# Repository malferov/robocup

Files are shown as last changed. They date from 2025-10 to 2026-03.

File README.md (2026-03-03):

# RoboCup Junior

Netherlands team CoreX

<p align="center">
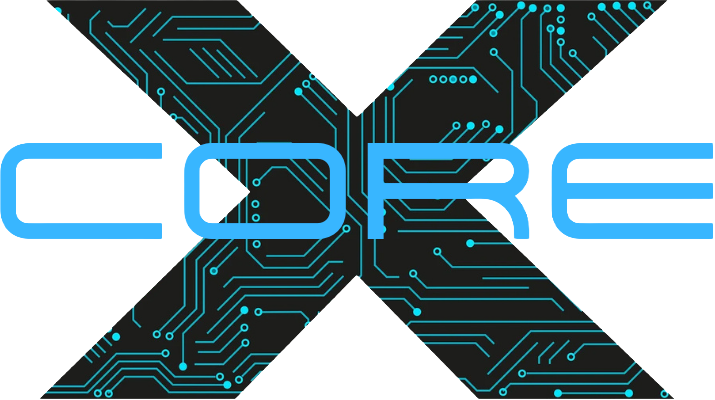
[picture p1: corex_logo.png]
CoreX
    
</p>

# Components
- 25mm DC 12V GA-370 Low Speed Metal Gear Motor 400RPM 3.5 Watts 90 g
- TB6612FNG Dual Driver Controller Board MOSFET H Bridge 15V max VCC=2.7-5.5V Output 1.2A/3.2A
- 12.6V 3000mAh Lithium Ion Battery 157 g
- OT253-B47 Step-down buck converter 4.5-24V to 5V 3A
- HC-SR04 Ultrasonic Sensor
- TCRT5000 Reflective Infrared Optical Sensor
- TSSP4038, 38kHz IR Receiver, 950nm ±45°, 25m Range, 2.5-5.5V
- HC4067 16-channel Analog Multiplexer
- BMM150 Triple Axis Magnetometer Sensor
- MCU: ESP32-S3

# Metrics
### Consumption
- Main + CAM + Driver: 170 mA
### Performance
- Distance sensor: 33 ms
- Camera capture: 34 ms
- get_pos: 98 ms

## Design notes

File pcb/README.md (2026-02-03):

# CNC

lift tool `G0 Z5`  
return to origin `G0 X0 Y0`

# PCB

default net class
- clearance 0.5 mm
- track width 1 mm
- via size 2 mm
- via hole 0.8

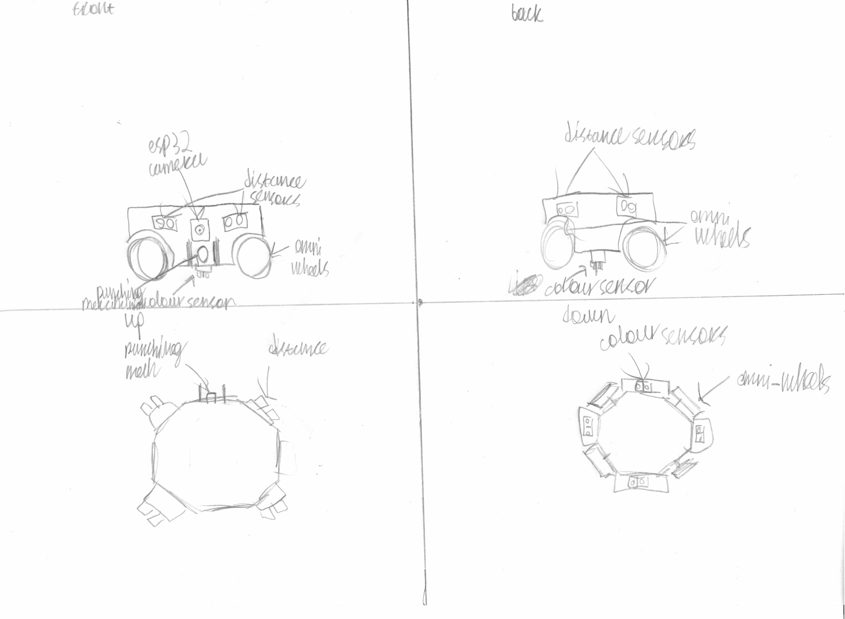
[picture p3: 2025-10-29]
docs/design_concept.jpg

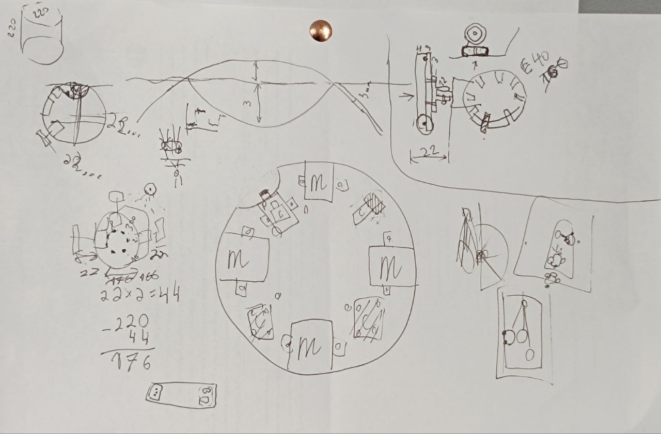
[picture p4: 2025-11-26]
docs/design_body.jpg

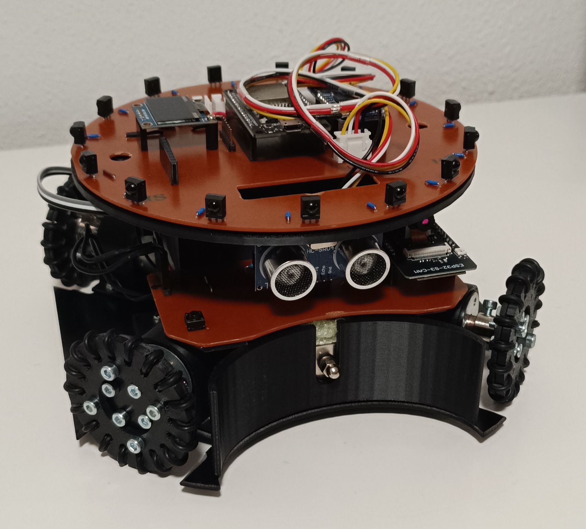
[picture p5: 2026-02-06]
docs/bot1.jpg

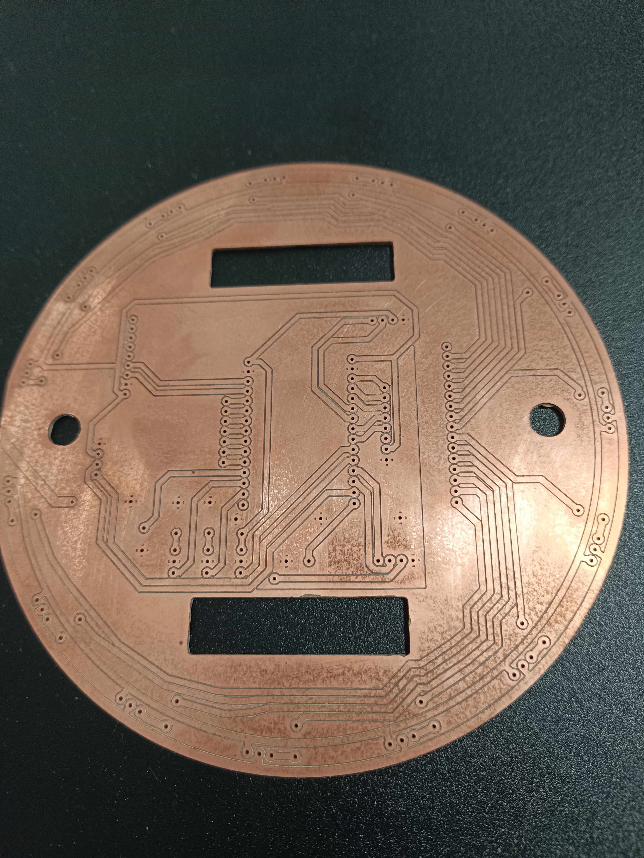
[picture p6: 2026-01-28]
docs/mainboard.jpg

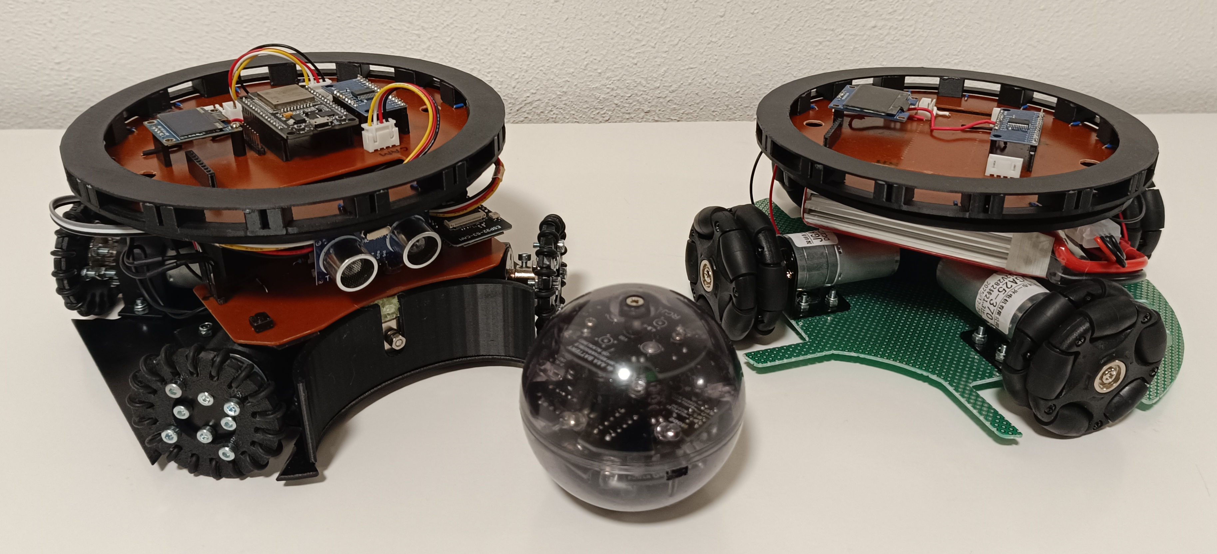
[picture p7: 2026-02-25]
docs/robots.jpg

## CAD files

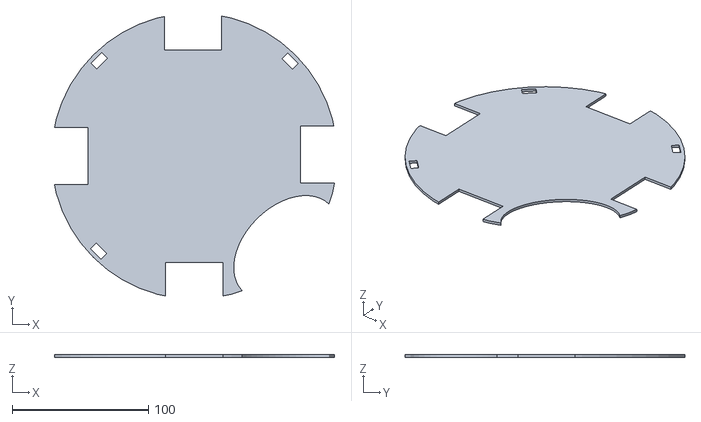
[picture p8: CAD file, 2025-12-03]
pintables/body/body.stl
205.6 x 205.5 x 2.00

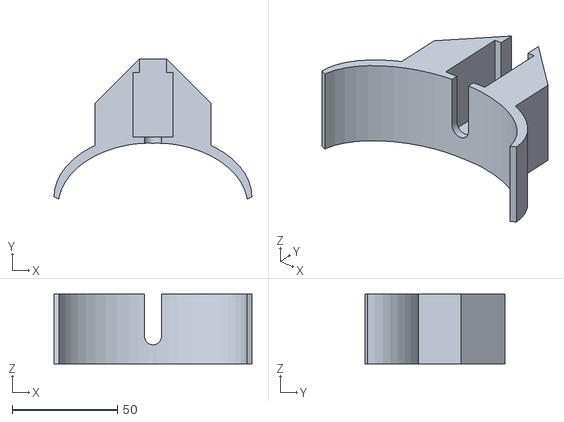
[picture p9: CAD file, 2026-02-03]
pintables/front_bumper.stl
94.0 x 66.6 x 33.0

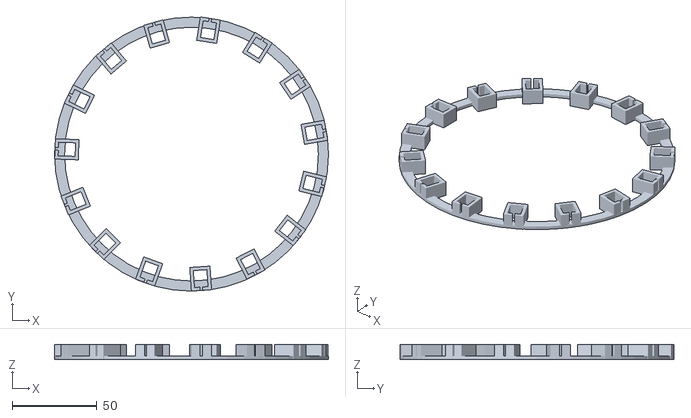
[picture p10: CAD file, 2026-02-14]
pintables/IRcase/IR_case.stl
162.0 x 162.1 x 9.00

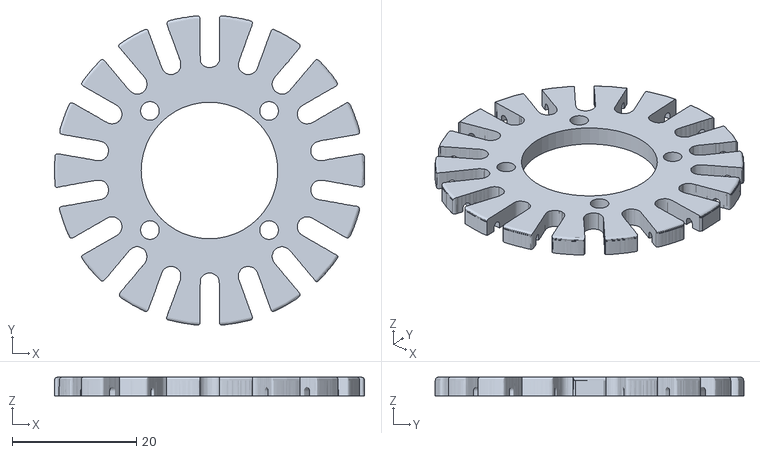
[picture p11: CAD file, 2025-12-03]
pintables/wheel/star_cap.stl
50.0 x 49.8 x 3.00

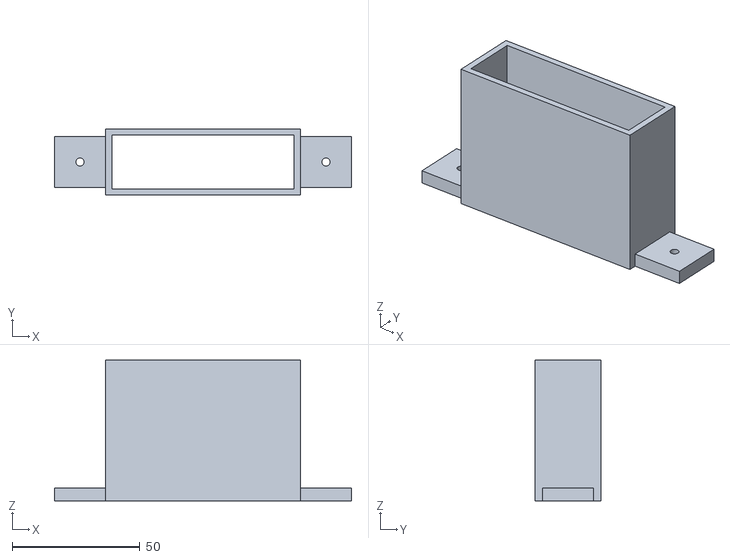
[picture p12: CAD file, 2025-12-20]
pintables/battery_holder.stl
116.3 x 26.0 x 55.2

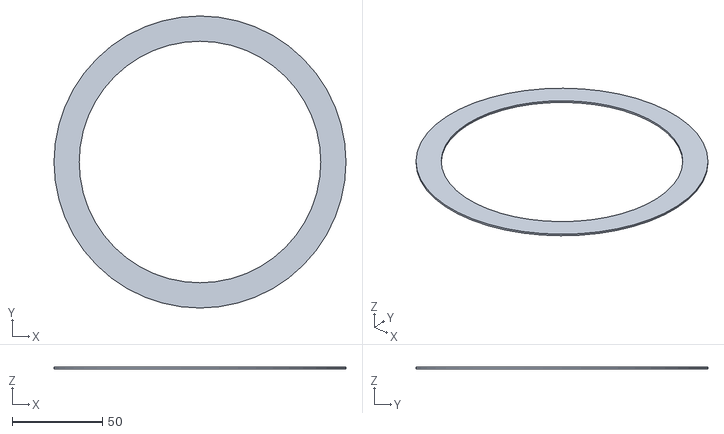
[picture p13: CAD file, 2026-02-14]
pintables/IRcase/IR_case_top.stl
162.0 x 162.0 x 1

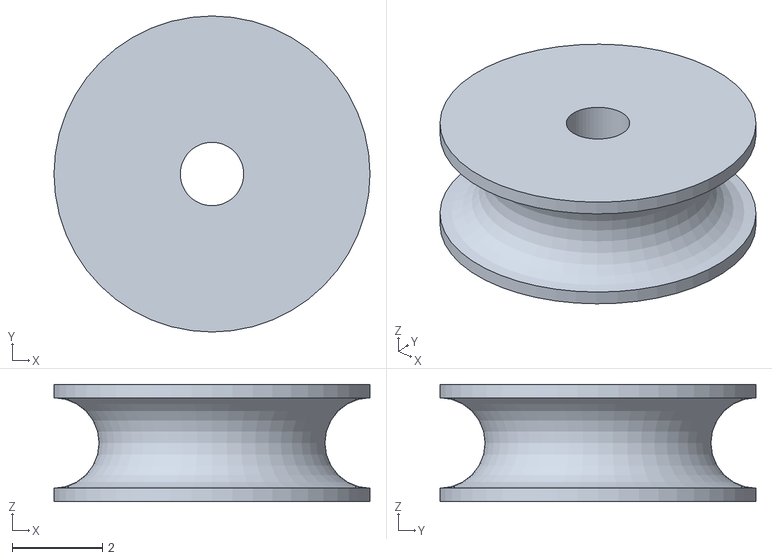
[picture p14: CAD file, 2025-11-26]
pintables/wheel/pulley.stl
7.00 x 7.00 x 2.60

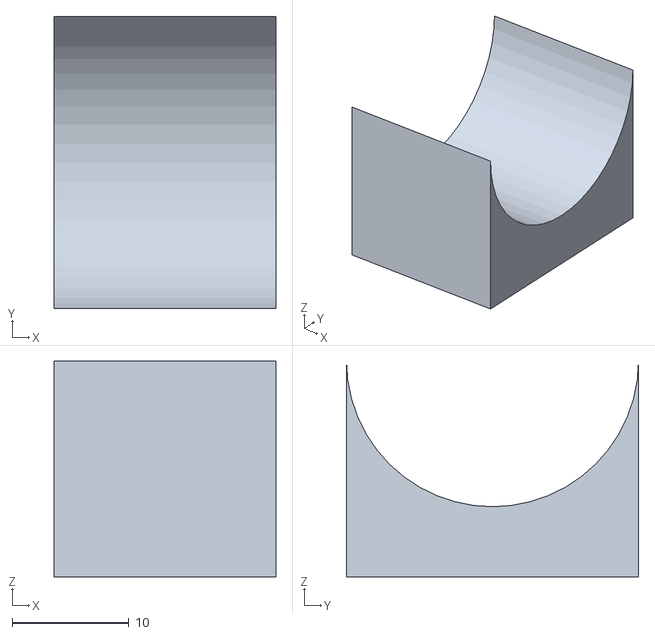
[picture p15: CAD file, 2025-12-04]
pintables/support.stl
19.0 x 25.0 x 18.5

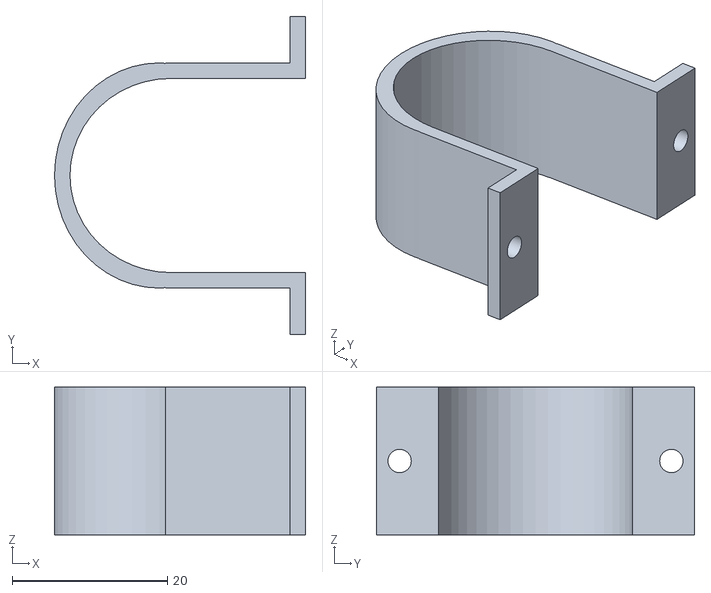
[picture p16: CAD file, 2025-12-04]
pintables/arc.stl
32.3 x 41.0 x 19.0

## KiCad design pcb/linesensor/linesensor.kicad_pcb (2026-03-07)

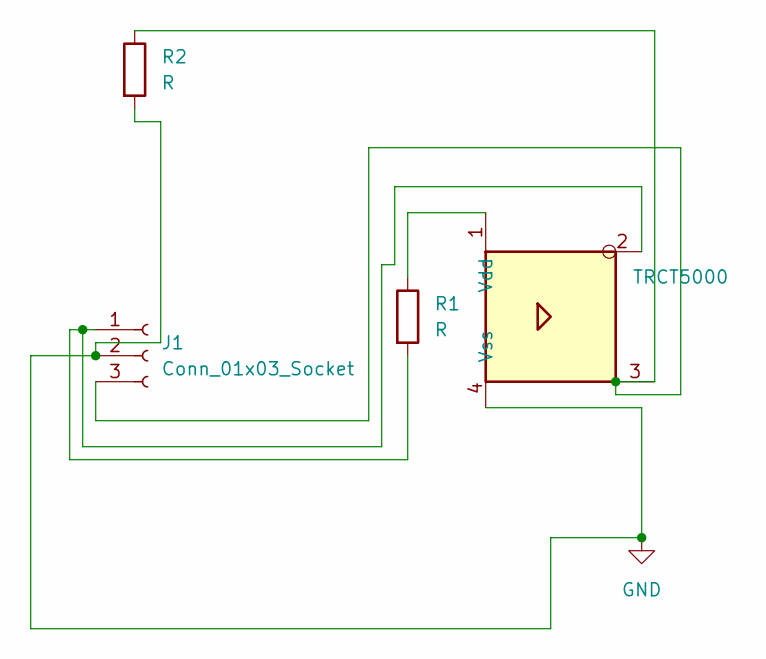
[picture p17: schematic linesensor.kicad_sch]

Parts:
J1: Conn_01x03_Socket; PinSocket_1x03_P2.54mm_Vertical
R1, R2: R; R_Axial_DIN0309_L9.0mm_D3.2mm_P12.70mm_Horizontal
U1: TRCT5000; CRT5000

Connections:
GND: J1.2, R2.2, U1.4 (Vss)
unnamed: J1.1, R1.2, U1.2
unnamed: J1.3, R2.1, U1.3
unnamed: R1.1, U1.1 (Vdd)

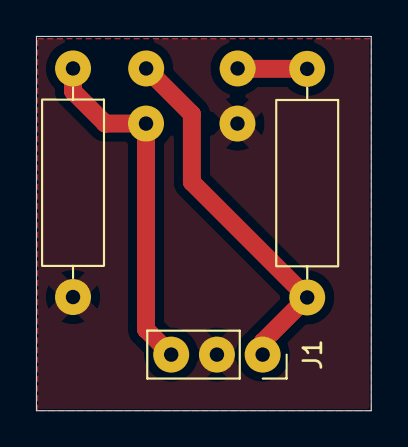
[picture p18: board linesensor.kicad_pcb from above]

Board: 2 copper layers, 18.6 x 20.8 mm, 4 parts (0 on the bottom side), 4 nets.

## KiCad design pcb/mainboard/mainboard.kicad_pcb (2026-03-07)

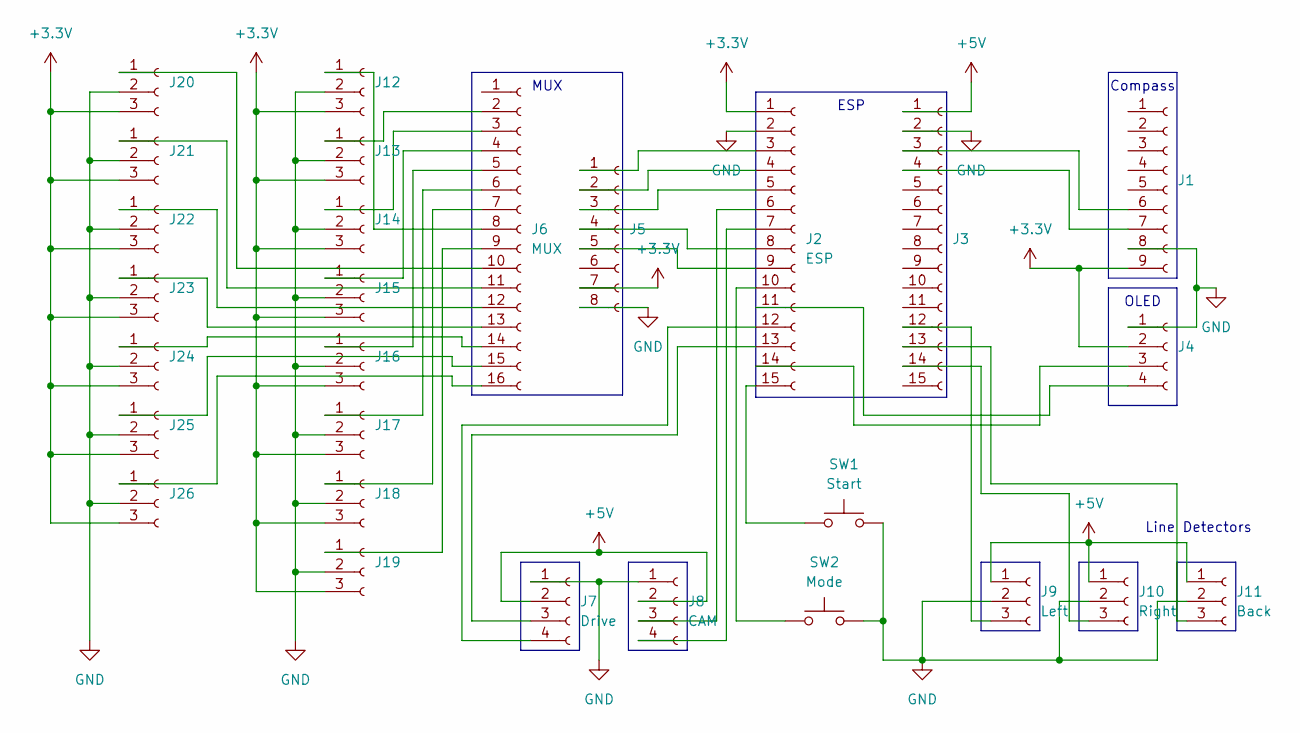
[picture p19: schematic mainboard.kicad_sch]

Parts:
J1: Compass; PinSocket_1x09_P2.54mm_Vertical
J2: ESP; PinSocket_1x15_P2.54mm_Vertical
J3: ESP_; PinSocket_1x15_P2.54mm_Vertical
J4: OLED; PinSocket_1x04_P2.54mm_Vertical
J5: MUX_; PinSocket_1x08_P2.54mm_Vertical
J6: MUX; PinSocket_1x16_P2.54mm_Vertical
J7: Drive; PinSocket_1x04_P2.54mm_Vertical
J8: CAM; PinSocket_1x04_P2.54mm_Vertical
J9: Left; PinSocket_1x03_P2.54mm_Vertical
J10: Right; PinSocket_1x03_P2.54mm_Vertical
J11: Back; PinSocket_1x03_P2.54mm_Vertical
J12, J13, J14, J15, J16, J17, J18, J19, J20, J21, J22, J23, J24, J25, J26: Conn_01x03_Socket; PinSocket_1x03_P2.54mm_Vertical
SW1: Start; D_5W_P5.08mm_Vertical_AnodeUp
SW2: Mode; D_5W_P5.08mm_Vertical_AnodeUp

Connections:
+3.3V: J1.9, J2.1, J4.2, J5.7, J12.3, J13.3, J14.3, J15.3, J16.3, J17.3, J18.3, J19.3, J20.3, J21.3, J22.3, J23.3, J24.3, J25.3, J26.3
+5V: J3.1, J7.2, J8.2, J9.1, J10.1, J11.1
GND: J1.8, J2.2, J3.2, J4.1, J5.8, J7.1, J8.1, J9.2, J10.2, J11.2, J12.2, J13.2, J14.2, J15.2, J16.2, J17.2, J18.2, J19.2, J20.2, J21.2, J22.2, J23.2, J24.2, J25.2, J26.2, SW1.2, SW2.2
unnamed: J1.6, J3.3
unnamed: J1.7, J3.4
unnamed: J2.3, J5.1
unnamed: J2.4, J5.2
unnamed: J2.5, J5.3
unnamed: J2.6, J8.3
unnamed: J2.7, J8.4
unnamed: J2.8, J5.4
unnamed: J2.9, J5.5
unnamed: J2.10, SW2.1
unnamed: J2.11, J4.4
unnamed: J2.12, J7.4
unnamed: J2.13, J7.3
unnamed: J2.14, J4.3
unnamed: J2.15, SW1.1
unnamed: J3.12, J9.3
unnamed: J3.14, J10.3
unnamed: J3.13, J11.3
unnamed: J6.8, J12.1
unnamed: J6.2, J13.1
unnamed: J6.3, J14.1
unnamed: J6.4, J15.1
unnamed: J6.5, J16.1
unnamed: J6.6, J17.1
unnamed: J6.7, J18.1
unnamed: J6.9, J19.1
unnamed: J6.10, J20.1
unnamed: J6.11, J21.1
unnamed: J6.12, J22.1
unnamed: J6.13, J23.1
unnamed: J6.14, J24.1
unnamed: J6.15, J25.1
unnamed: J6.16, J26.1

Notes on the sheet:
Line Detectors
OLED
Compass
ESP
MUX

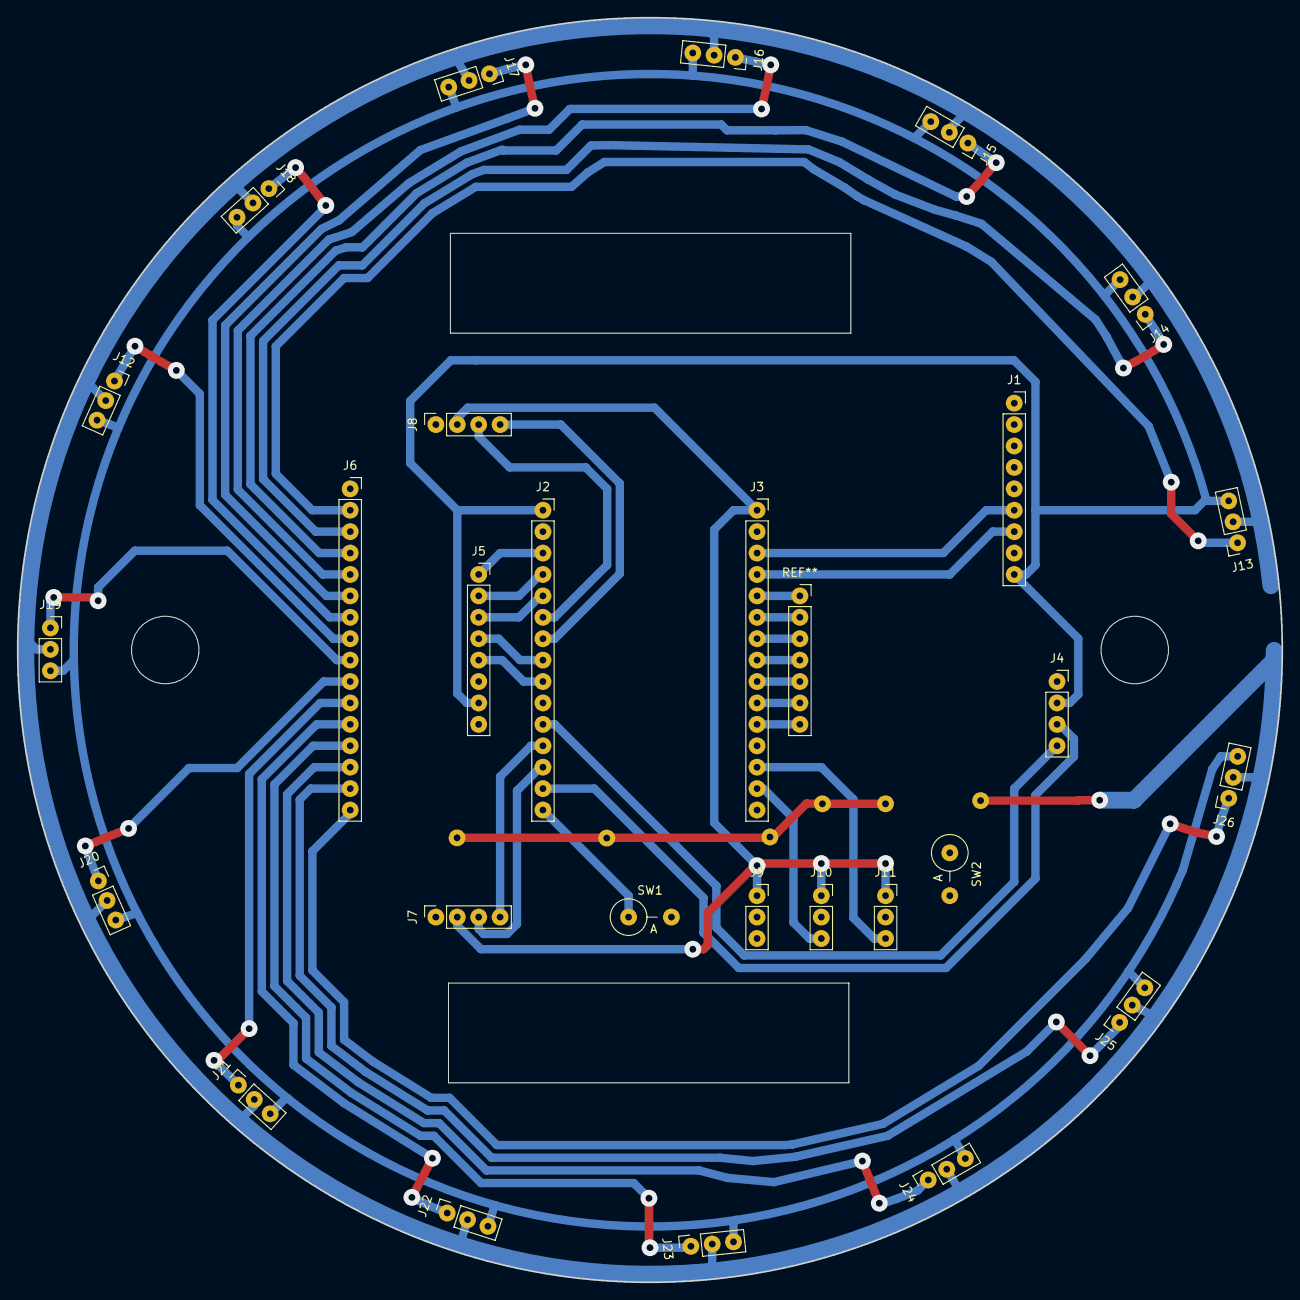
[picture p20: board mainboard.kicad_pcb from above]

Board: 2 copper layers, 150.0 x 150.0 mm, 28 parts (0 on the bottom side), 36 nets.

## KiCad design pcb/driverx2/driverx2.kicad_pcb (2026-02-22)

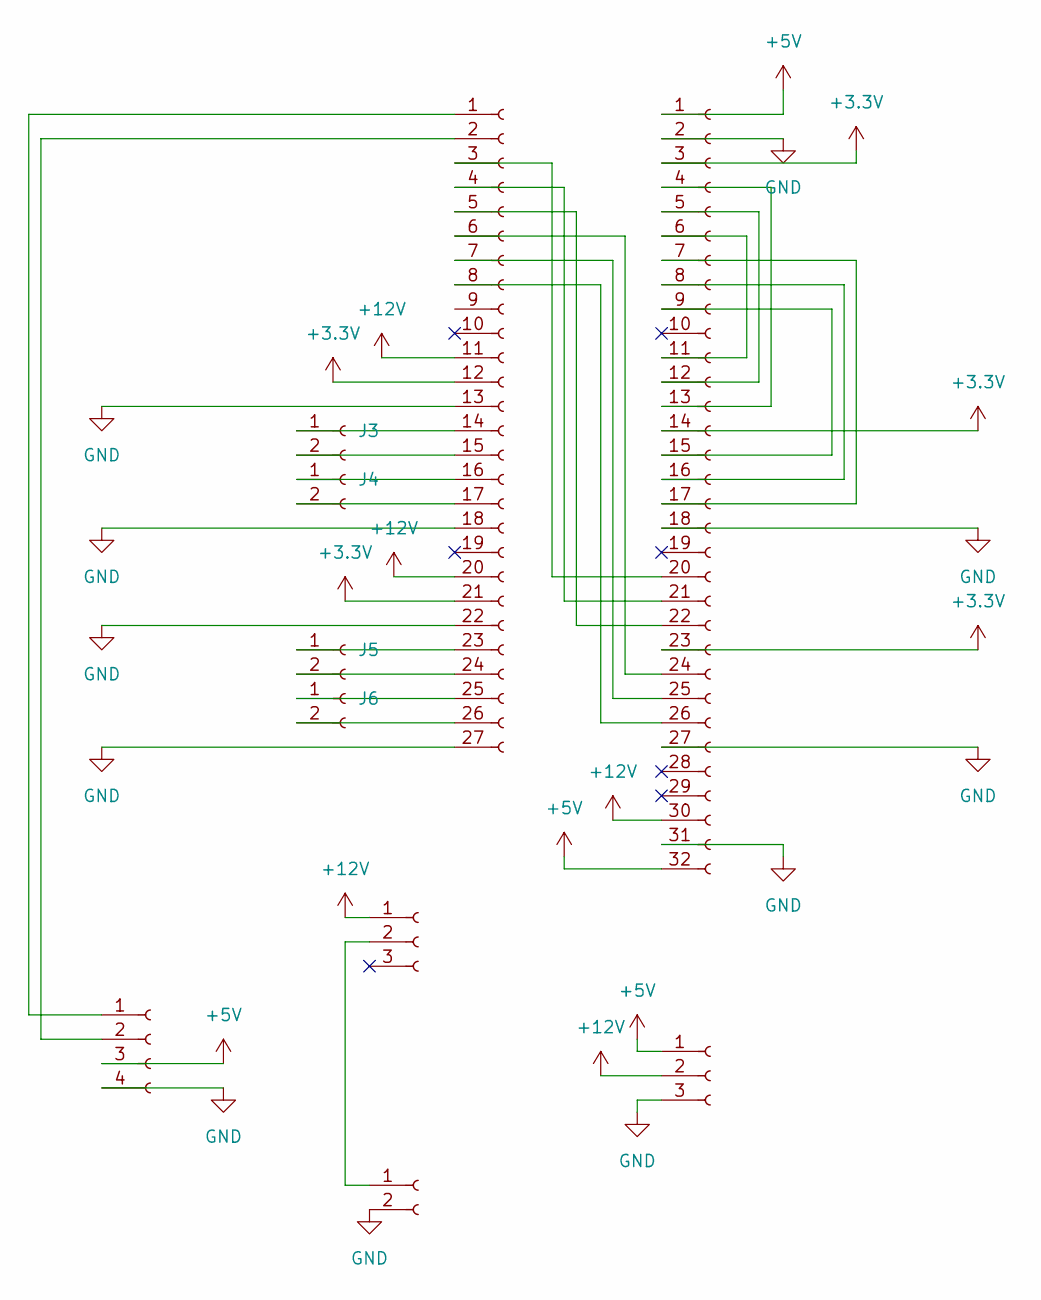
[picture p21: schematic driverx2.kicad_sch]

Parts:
J1: Conn_01x32_Socket; PinHeader_1x32_P2.54mm_Vertical
J2, J10: Conn_01x03_Socket; PinHeader_1x03_P2.54mm_Vertical
J3, J4, J5, J6, J9: Conn_01x02_Socket; PinHeader_1x02_P2.54mm_Vertical
J7: Conn_01x04_Socket; PinHeader_1x04_P2.54mm_Vertical
J8: Conn_01x27_Socket; PinHeader_1x27_P2.54mm_Vertical

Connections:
+3.3V: J1.3, J1.14, J1.23, J8.12, J8.21
+5V: J1.1, J1.32, J7.3, J10.1
+12V: J1.30, J2.1, J8.11, J8.20, J10.2
GND: J1.2, J1.18, J1.27, J1.31, J7.4, J8.13, J8.18, J8.22, J8.27, J9.2, J10.3
unnamed: J1.6, J1.11
unnamed: J1.5, J1.12
unnamed: J1.4, J1.13
unnamed: J1.9, J1.15
unnamed: J1.8, J1.16
unnamed: J1.7, J1.17
unnamed: J1.20, J8.3
unnamed: J1.21, J8.4
unnamed: J1.22, J8.5
unnamed: J1.24, J8.6
unnamed: J1.25, J8.7
unnamed: J1.26, J8.8
unnamed: J2.2, J9.1
unnamed: J3.1, J8.14
unnamed: J3.2, J8.15
unnamed: J4.1, J8.16
unnamed: J4.2, J8.17
unnamed: J5.1, J8.23
unnamed: J5.2, J8.24
unnamed: J6.1, J8.25
unnamed: J6.2, J8.26
unnamed: J7.1, J8.1
unnamed: J7.2, J8.2

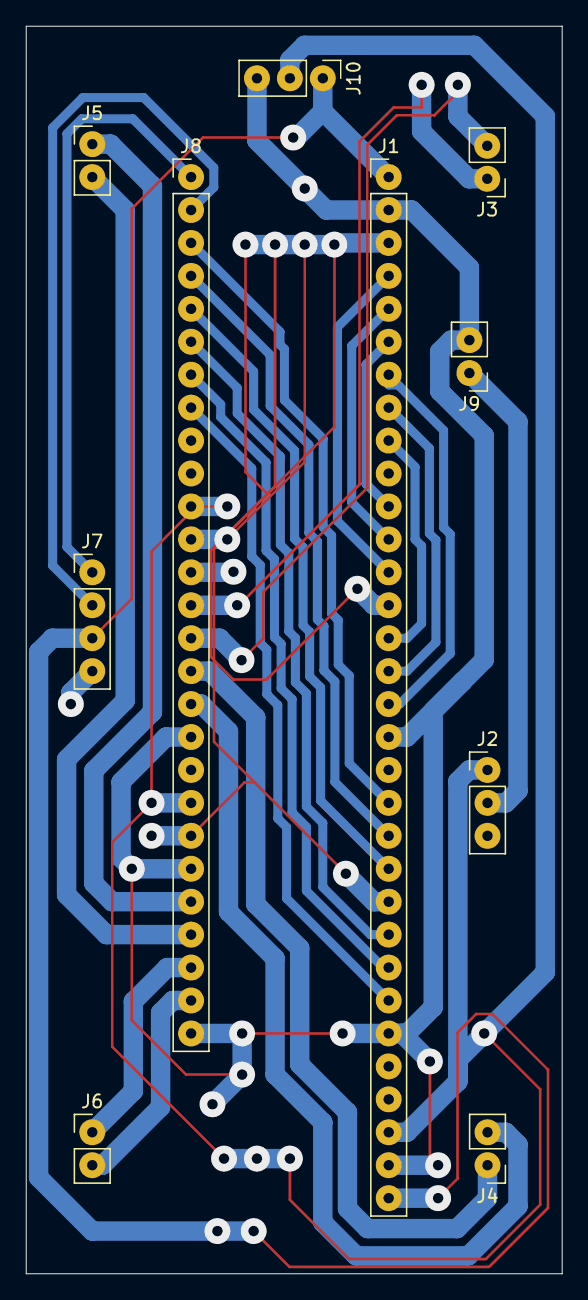
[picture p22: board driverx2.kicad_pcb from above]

Board: 2 copper layers, 41.3 x 96.2 mm, 10 parts (0 on the bottom side), 27 nets.

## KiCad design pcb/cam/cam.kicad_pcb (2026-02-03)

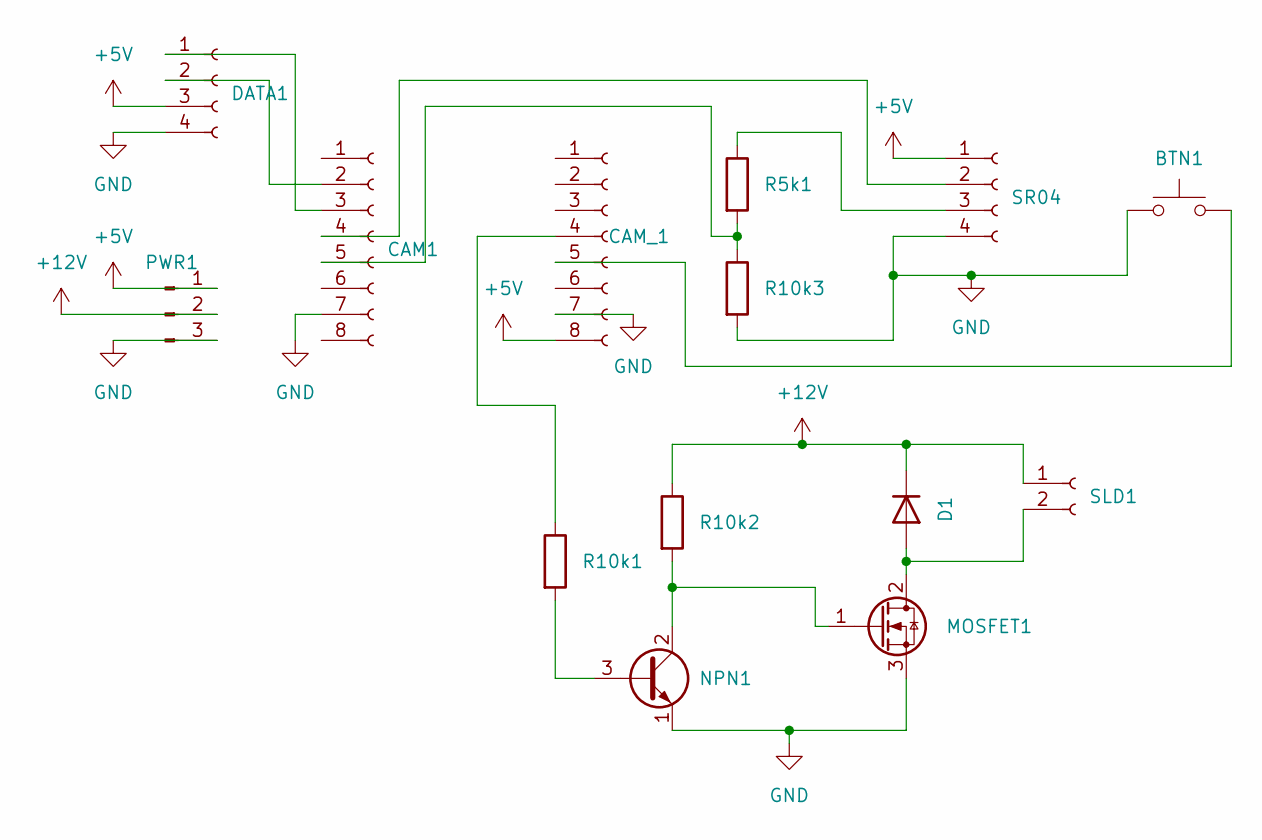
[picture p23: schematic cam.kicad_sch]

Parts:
BTN1: SW_Push; D_DO-41_SOD81_P5.08mm_Vertical_KathodeUp
CAM1: Conn_01x08_Socket; PinSocket_1x08_P2.54mm_Vertical
CAM_1: Conn_01x08_Socket; PinSocket_1x08_P2.54mm_Vertical
D1: 1N4001; D_DO-41_SOD81_P10.16mm_Horizontal
DATA1: Conn_01x04_Socket; PinSocket_1x04_P2.54mm_Vertical
MOSFET1: IRF840A; TO-220-3_Vertical
NPN1: 2SC1815; PinHeader_1x03_P2.54mm_Vertical
PWR1: Conn_01x03_Pin; PinHeader_1x03_P2.54mm_Vertical
R5k1, R10k1, R10k2, R10k3: R; R_Axial_DIN0207_L6.3mm_D2.5mm_P10.16mm_Horizontal
SLD1: Conn_01x02_Socket; PinHeader_1x02_P2.54mm_Vertical
SR04: Conn_01x04_Socket; PinSocket_1x04_P2.54mm_Vertical

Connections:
+5V: CAM_1.8, DATA1.3, PWR1.1, SR04.1
+12V: D1.1 (K), PWR1.2, R10k2.1, SLD1.1
GND: BTN1.1, CAM1.7, CAM_1.7, DATA1.4, MOSFET1.3 (S), NPN1.1 (E), PWR1.3, R10k3.2, SR04.4
unnamed: CAM1.2, DATA1.2
unnamed: CAM1.3, DATA1.1
unnamed: CAM1.4, SR04.2
unnamed: CAM1.5, R5k1.2, R10k3.1
unnamed: CAM_1.4, R10k1.1
unnamed: BTN1.2, CAM_1.5
unnamed: D1.2 (A), MOSFET1.2 (D), SLD1.2
unnamed: MOSFET1.1 (G), NPN1.2 (C), R10k2.2
unnamed: NPN1.3 (B), R10k1.2
unnamed: R5k1.1, SR04.3

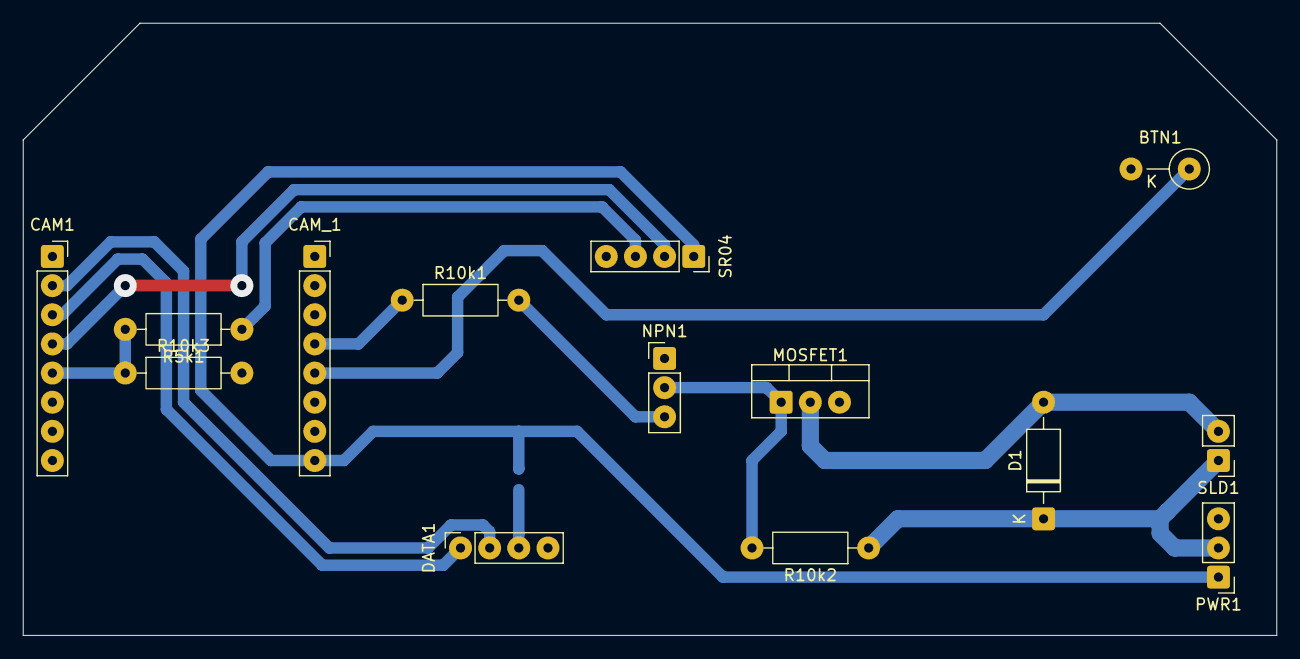
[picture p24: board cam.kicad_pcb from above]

Board: 2 copper layers, 109.2 x 53.3 mm, 14 parts (0 on the bottom side), 13 nets.

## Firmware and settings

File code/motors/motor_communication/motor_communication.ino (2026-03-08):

#define RAMP_MAX 255
#define RAMP_STEP 1
#define MOTOR_TIME 15000 // ms

// motors[motor][pin]
// pin 0 = DIR1
// pin 1 = DIR2
// pin 2 = PWM

#define BOT_ID 1 // 1 or 2

#if BOT_ID == 1
const int motors[4][3] = {
  {9, 10, 8},    // Motor RF1
  {2, 7, 3},     // Motor RB2
  {5, 4, 6},     // Motor LB3
  {12, 11, 13}   // Motor LF4
};
#else
const int motors[4][3] = {
  {2, 3, 1},     // Motor RF1 2A
  {12, 13, 11},  // Motor RB2 1A
  {8, 9, 10},    // Motor LB3 1B
  {4, 5, 6}      // Motor LF4 2B
};
#endif

int targetRF1 = 0;
int targetRB2 = 0;
int targetLB3 = 0;
int targetLF4 = 0;

int currentRF1 = 0;
int currentRB2 = 0;
int currentLB3 = 0;
int currentLF4 = 0;

String getValue(String data, char separator, int index) {
  int found = 0;
  int strIndex[] = {0, -1};
  int maxIndex = data.length()-1;

  for(int i=0; i<=maxIndex && found<=index; i++){
    if(data.charAt(i)==separator || i==maxIndex){
        found++;
        strIndex[0] = strIndex[1]+1;
        strIndex[1] = (i == maxIndex) ? i+1 : i;
    }
  }
  return found>index ? data.substring(strIndex[0], strIndex[1]) : "";
}

// 1 = 1,0 forward
// 0 = 0,1 reverse
void set_dir_motor(int dir, int pin_1, int pin_2) {
  if (dir == 1) {
    digitalWrite(pin_1, 1);
    digitalWrite(pin_2, 0);
  } else {
    digitalWrite(pin_1, 0);
    digitalWrite(pin_2, 1);
  }
}

void dir_move_all(int max, int min, int dir, int time) {

  // limit max, min & time
  if (max > RAMP_MAX) { max = RAMP_MAX; }
  if (max < 0) { max = 0; }
  if (min > max) { min = max; }
  if (min < 0) { min = 0; }
  if (time > MOTOR_TIME) { time = MOTOR_TIME; }
  if (time < 0) { time = 0; }

  // ---- SET DIRECTION ----
  if (dir == 0) {                 // FORWARD
    for (int m = 0; m < 4; m++) {
      set_dir_motor(1, motors[m][0], motors[m][1]);
    }

  } else if (dir == 180) {        // BACKWARD
    for (int m = 0; m < 4; m++) {
      set_dir_motor(0, motors[m][0], motors[m][1]);
    }

  } else if (dir == 90) {         // SLIDE RIGHT
    set_dir_motor(0, motors[0][0], motors[0][1]);
    set_dir_motor(1, motors[1][0], motors[1][1]);
    set_dir_motor(0, motors[2][0], motors[2][1]);
    set_dir_motor(1, motors[3][0], motors[3][1]);

  } else if (dir == 270) {        // SLIDE LEFT
    set_dir_motor(1, motors[0][0], motors[0][1]);
    set_dir_motor(0, motors[1][0], motors[1][1]);
    set_dir_motor(1, motors[2][0], motors[2][1]);
    set_dir_motor(0, motors[3][0], motors[3][1]);

  } else {
    return; // invalid direction
  }

  // ---- RAMP UP ----
  for (int duty = min; duty <= max; duty++) {
    for (int m = 0; m < 4; m++) {
      analogWrite(motors[m][2], duty);
    }
    delay(1);
  }
  delay(time);
  // ---- RAMP DOWN ----
  for (int duty = max; duty >= 0; duty--) {
    for (int m = 0; m < 4; m++) {
      analogWrite(motors[m][2], duty);
    }
    delay(1);
  }
}

void speed4(int FL, int FR, int RR, int RL, int time) {

  // limit speed
  int speed[4] = {FL, FR, RR, RL};
  for (int m = 0; m < 4; m++) {
    if (speed[m] > RAMP_MAX) { speed[m] = RAMP_MAX; }
    if (speed[m] < -RAMP_MAX) { speed[m] = -RAMP_MAX; }
  }
  // limit time
  if (time > MOTOR_TIME) { time = MOTOR_TIME; }
  if (time < 0) { time = 0; }
  // set direction
  for (int m = 0; m < 4; m++) {
    if (speed[m] > 0) {
      set_dir_motor(1, motors[m][0], motors[m][1]);
    } else {
      set_dir_motor(0, motors[m][0], motors[m][1]);
    }
    // clear direction (for ramping)
    speed[m] = abs(speed[m]);
  }
  // ---- RAMP UP ----
  for (int duty = 0; duty <= RAMP_MAX; duty++) {
    bool done[4] = {false, false, false, false};
    for (int m = 0; m < 4; m++) {
      if (speed[m] >= duty) {
        analogWrite(motors[m][2], duty);
      } else {
        done[m] = true;
      }
    }
    delay(1);
    if (done[0] && done[1] && done[2] && done[3]) {
      break;
    }
  }
  // ---- RUN ----
  delay(time);
  // ---- RAMP DOWN ----
  for (int duty = 0; duty <= RAMP_MAX; duty++) {
    bool done[4] = {false, false, false, false};
    for (int m = 0; m < 4; m++) {
      if (speed[m] >= duty) {
        analogWrite(motors[m][2], speed[m] - duty); // invert
      } else {
        done[m] = true;
      }
    }
    delay(1);
    if (done[0] && done[1] && done[2] && done[3]) {
      break;
    }
  }
}

void rampMotor(int motor, int *current, int target) {
    int m = motor-1;
    // ramp current
    if (*current < target) {
        *current += RAMP_STEP;
        if (*current > target)
            *current = target;
    }
    else if (*current > target) {
        *current -= RAMP_STEP;
        if (*current < target)
            *current = target;
    }
    // set direction
    if (abs(*current) <= RAMP_STEP) {
        if (*current > 0) {
            set_dir_motor(1, motors[m][0], motors[m][1]);
        } else {
            set_dir_motor(0, motors[m][0], motors[m][1]);
        }
    }
    // set pwm
    analogWrite(motors[m][2], abs(*current));
}

void stop() {
  // set target zero
  targetRF1 = 0;
  targetRB2 = 0;
  targetLB3 = 0;
  targetLF4 = 0;
  // define max pwm
  int max = 0;
  if (abs(currentRF1) > max) max = abs(currentRF1);
  if (abs(currentRB2) > max) max = abs(currentRB2);
  if (abs(currentLB3) > max) max = abs(currentLB3);
  if (abs(currentLF4) > max) max = abs(currentLF4);
  // ramp down
  for (int duty = 0; duty <= max; duty++) {
    rampMotor(1, &currentRF1, targetRF1);
    rampMotor(2, &currentRB2, targetRB2);
    rampMotor(3, &currentLB3, targetLB3);
    rampMotor(4, &currentLF4, targetLF4);
    delay(1);
  }
}

void setup() {
  Serial.begin(9600);
  for (int m = 0; m < 4; m++) {
    for (int p = 0; p < 3; p++) {
      pinMode(motors[m][p], OUTPUT);
    }
  }
}

void loop() {
  if (Serial.available()) {
    String command_raw = Serial.readStringUntil('\n');
    String command = getValue(command_raw, ':', 0);
    if (command == "dir_move_all") {
      int arg1 = getValue(command_raw, ':', 1).toInt();
      int arg2 = getValue(command_raw, ':', 2).toInt();
      int arg3 = getValue(command_raw, ':', 3).toInt();
      int arg4 = getValue(command_raw, ':', 4).toInt();
      stop();
      dir_move_all(arg1, arg2, arg3, arg4);
    } else if (command == "speed4") {
      int arg1 = getValue(command_raw, ':', 1).toInt();
      int arg2 = getValue(command_raw, ':', 2).toInt();
      int arg3 = getValue(command_raw, ':', 3).toInt();
      int arg4 = getValue(command_raw, ':', 4).toInt();
      int arg5 = getValue(command_raw, ':', 5).toInt();
      stop();
      speed4(arg1, arg2, arg3, arg4, arg5);
    } else if (command == "target") {
      targetRF1 = getValue(command_raw, ':', 1).toInt();
      targetRB2 = getValue(command_raw, ':', 2).toInt();
      targetLB3 = getValue(command_raw, ':', 3).toInt();
      targetLF4 = getValue(command_raw, ':', 4).toInt();
      // debug
      //Serial.printf("cmd %s, arg1 %d, arg2 %d, arg3 %d, arg4 %d\n", command, targetRF1, targetRB2, targetLB3, targetLF4);
    }
  }

  rampMotor(1, &currentRF1, targetRF1);
  rampMotor(2, &currentRB2, targetRB2);
  rampMotor(3, &currentLB3, targetLB3);
  rampMotor(4, &currentLF4, targetLF4);

  delay(1);
}

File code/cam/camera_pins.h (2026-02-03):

#if defined(CAMERA_MODEL_WROVER_KIT)
#define PWDN_GPIO_NUM  -1
#define RESET_GPIO_NUM -1
#define XCLK_GPIO_NUM  21
#define SIOD_GPIO_NUM  26
#define SIOC_GPIO_NUM  27

#define Y9_GPIO_NUM    35
#define Y8_GPIO_NUM    34
#define Y7_GPIO_NUM    39
#define Y6_GPIO_NUM    36
#define Y5_GPIO_NUM    19
#define Y4_GPIO_NUM    18
#define Y3_GPIO_NUM    5
#define Y2_GPIO_NUM    4
#define VSYNC_GPIO_NUM 25
#define HREF_GPIO_NUM  23
#define PCLK_GPIO_NUM  22

#elif defined(CAMERA_MODEL_ESP_EYE)
#define PWDN_GPIO_NUM  -1
#define RESET_GPIO_NUM -1
#define XCLK_GPIO_NUM  4
#define SIOD_GPIO_NUM  18
#define SIOC_GPIO_NUM  23

#define Y9_GPIO_NUM    36
#define Y8_GPIO_NUM    37
#define Y7_GPIO_NUM    38
#define Y6_GPIO_NUM    39
#define Y5_GPIO_NUM    35
#define Y4_GPIO_NUM    14
#define Y3_GPIO_NUM    13
#define Y2_GPIO_NUM    34
#define VSYNC_GPIO_NUM 5
#define HREF_GPIO_NUM  27
#define PCLK_GPIO_NUM  25

#define LED_GPIO_NUM 22

#elif defined(CAMERA_MODEL_M5STACK_PSRAM)
#define PWDN_GPIO_NUM  -1
#define RESET_GPIO_NUM 15
#define XCLK_GPIO_NUM  27
#define SIOD_GPIO_NUM  25
#define SIOC_GPIO_NUM  23

#define Y9_GPIO_NUM    19
#define Y8_GPIO_NUM    36
#define Y7_GPIO_NUM    18
#define Y6_GPIO_NUM    39
#define Y5_GPIO_NUM    5
#define Y4_GPIO_NUM    34
#define Y3_GPIO_NUM    35
#define Y2_GPIO_NUM    32
#define VSYNC_GPIO_NUM 22
#define HREF_GPIO_NUM  26
#define PCLK_GPIO_NUM  21

#elif defined(CAMERA_MODEL_M5STACK_V2_PSRAM)
#define PWDN_GPIO_NUM  -1
#define RESET_GPIO_NUM 15
#define XCLK_GPIO_NUM  27
#define SIOD_GPIO_NUM  22
#define SIOC_GPIO_NUM  23

#define Y9_GPIO_NUM    19
#define Y8_GPIO_NUM    36
#define Y7_GPIO_NUM    18
#define Y6_GPIO_NUM    39
#define Y5_GPIO_NUM    5
#define Y4_GPIO_NUM    34
#define Y3_GPIO_NUM    35
#define Y2_GPIO_NUM    32
#define VSYNC_GPIO_NUM 25
#define HREF_GPIO_NUM  26
#define PCLK_GPIO_NUM  21

#elif defined(CAMERA_MODEL_M5STACK_WIDE)
#define PWDN_GPIO_NUM  -1
#define RESET_GPIO_NUM 15
#define XCLK_GPIO_NUM  27
#define SIOD_GPIO_NUM  22
#define SIOC_GPIO_NUM  23

#define Y9_GPIO_NUM    19
#define Y8_GPIO_NUM    36
#define Y7_GPIO_NUM    18
#define Y6_GPIO_NUM    39
#define Y5_GPIO_NUM    5
#define Y4_GPIO_NUM    34
#define Y3_GPIO_NUM    35
#define Y2_GPIO_NUM    32
#define VSYNC_GPIO_NUM 25
#define HREF_GPIO_NUM  26
#define PCLK_GPIO_NUM  21

#define LED_GPIO_NUM 2

#elif defined(CAMERA_MODEL_M5STACK_ESP32CAM)
#define PWDN_GPIO_NUM  -1
#define RESET_GPIO_NUM 15
#define XCLK_GPIO_NUM  27
#define SIOD_GPIO_NUM  25
#define SIOC_GPIO_NUM  23

#define Y9_GPIO_NUM    19
#define Y8_GPIO_NUM    36
#define Y7_GPIO_NUM    18
#define Y6_GPIO_NUM    39
#define Y5_GPIO_NUM    5
#define Y4_GPIO_NUM    34
#define Y3_GPIO_NUM    35
#define Y2_GPIO_NUM    17
#define VSYNC_GPIO_NUM 22
#define HREF_GPIO_NUM  26
#define PCLK_GPIO_NUM  21

#elif defined(CAMERA_MODEL_M5STACK_UNITCAM)
#define PWDN_GPIO_NUM  -1
#define RESET_GPIO_NUM 15
#define XCLK_GPIO_NUM  27
#define SIOD_GPIO_NUM  25
#define SIOC_GPIO_NUM  23

#define Y9_GPIO_NUM    19
#define Y8_GPIO_NUM    36
#define Y7_GPIO_NUM    18
#define Y6_GPIO_NUM    39
#define Y5_GPIO_NUM    5
#define Y4_GPIO_NUM    34
#define Y3_GPIO_NUM    35
#define Y2_GPIO_NUM    32
#define VSYNC_GPIO_NUM 22
#define HREF_GPIO_NUM  26
#define PCLK_GPIO_NUM  21

#elif defined(CAMERA_MODEL_M5STACK_CAMS3_UNIT)
#define PWDN_GPIO_NUM  -1
#define RESET_GPIO_NUM 21
#define XCLK_GPIO_NUM  11
#define SIOD_GPIO_NUM  17
#define SIOC_GPIO_NUM  41

#define Y9_GPIO_NUM    13
#define Y8_GPIO_NUM    4
#define Y7_GPIO_NUM    10
#define Y6_GPIO_NUM    5
#define Y5_GPIO_NUM    7
#define Y4_GPIO_NUM    16
#define Y3_GPIO_NUM    15
#define Y2_GPIO_NUM    6
#define VSYNC_GPIO_NUM 42
#define HREF_GPIO_NUM  18
#define PCLK_GPIO_NUM  12

#define LED_GPIO_NUM 14

#elif defined(CAMERA_MODEL_AI_THINKER)
#define PWDN_GPIO_NUM  32
#define RESET_GPIO_NUM -1
#define XCLK_GPIO_NUM  0
#define SIOD_GPIO_NUM  26
#define SIOC_GPIO_NUM  27

#define Y9_GPIO_NUM    35
#define Y8_GPIO_NUM    34
#define Y7_GPIO_NUM    39
#define Y6_GPIO_NUM    36
#define Y5_GPIO_NUM    21
#define Y4_GPIO_NUM    19
#define Y3_GPIO_NUM    18
#define Y2_GPIO_NUM    5
#define VSYNC_GPIO_NUM 25
#define HREF_GPIO_NUM  23
#define PCLK_GPIO_NUM  22

// 4 for flash led or 33 for normal led
#define LED_GPIO_NUM   4

#elif defined(CAMERA_MODEL_TTGO_T_JOURNAL)
#define PWDN_GPIO_NUM  0
#define RESET_GPIO_NUM 15
#define XCLK_GPIO_NUM  27
#define SIOD_GPIO_NUM  25
#define SIOC_GPIO_NUM  23

#define Y9_GPIO_NUM    19
#define Y8_GPIO_NUM    36
#define Y7_GPIO_NUM    18
#define Y6_GPIO_NUM    39
#define Y5_GPIO_NUM    5
#define Y4_GPIO_NUM    34
#define Y3_GPIO_NUM    35
#define Y2_GPIO_NUM    17
#define VSYNC_GPIO_NUM 22
#define HREF_GPIO_NUM  26
#define PCLK_GPIO_NUM  21

#elif defined(CAMERA_MODEL_XIAO_ESP32S3)
#define PWDN_GPIO_NUM  -1
#define RESET_GPIO_NUM -1
#define XCLK_GPIO_NUM  10
#define SIOD_GPIO_NUM  40
#define SIOC_GPIO_NUM  39
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

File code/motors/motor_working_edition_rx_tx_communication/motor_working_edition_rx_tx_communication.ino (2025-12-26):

// const int pwmPinA_1 = 3;  
// const int pwmPinB_1 = 6;
// const int pinA_1_1 = 7;  
// const int pinA_2_1 = 2;  
// const int pinB_1_1 = 4;
// const int pinB_2_1 = 5;
// const int pwmPinA_2 = 13;  
// const int pwmPinB_2 = 8;
// const int pinA_1_2 = 12;  
// const int pinA_2_2 = 11;  
// const int pinB_1_2 = 10;
// const int pinB_2_2 = 9;
// motors[motor][pin]
// pin 0 = DIR1
// pin 1 = DIR2
// pin 2 = PWM

const int motors[4][3] = {
  {7, 2, 3},    // Motor 1
  {5, 4, 6},    // Motor 2
  {11, 12, 13}, // Motor 3
  {9, 10, 8}    // Motor 4
};

String getValue(String data, char separator, int index)
{
  int found = 0;
  int strIndex[] = {0, -1};
  int maxIndex = data.length()-1;

  for(int i=0; i<=maxIndex && found<=index; i++){
    if(data.charAt(i)==separator || i==maxIndex){
        found++;
        strIndex[0] = strIndex[1]+1;
        strIndex[1] = (i == maxIndex) ? i+1 : i;
    }
  }
  return found>index ? data.substring(strIndex[0], strIndex[1]) : "";
}

// 1 = 1,0
//0 = 0,1
void set_dir_motor(int buul,int pin_1, int pin_2) {
  if (buul == 1) {
    digitalWrite(pin_1, 1);
    digitalWrite(pin_2, 0);
  } else {
    digitalWrite(pin_1, 0);
    digitalWrite(pin_2, 1);
  }
}

void motor_jog_one(int max,int min, int p_pin, int dir , int d_pin_1, int d_pin_2, int time) 
{
  if (dir == 1) {
    digitalWrite(d_pin_1, 1);
    digitalWrite(d_pin_2, 0);
  } else {
    digitalWrite(d_pin_1, 0);
    digitalWrite(d_pin_2, 1);
  }
  for (int duty = min; duty <= max; duty++) {
    analogWrite(p_pin, duty);
    delay(1);
  }
  delay(time);
  for (int duty = max; duty >= 0; duty--) {
    analogWrite(p_pin, duty);
    delay(1);
  }
}
void motor_jog_double(int max, int min, int dir ,int time) {
  int m1 = 0;
  int m2 = 0;
  if (dir == 45) {
    m1 = 1;
    m2 = 3;
    set_dir_motor(0, motors[1][0], motors[1][1]);
    set_dir_motor(0, motors[3][0], motors[3][1]);
  } else if (dir == 135) {
    m1 = 0;
    m2 = 2;
    set_dir_motor(1, motors[0][0], motors[0][1]);
    set_dir_motor(1, motors[2][0], motors[2][1]);
  } else if (dir == 225) {
    m1 = 1;
    m2 = 3;
    set_dir_motor(1, motors[1][0], motors[1][1]);
    set_dir_motor(1, motors[3][0], motors[3][1]);
  } else if (dir == 315) {
    m1 = 0;
    m2 = 2;
    set_dir_motor(0, motors[0][0], motors[0][1]);
    set_dir_motor(0, motors[2][0], motors[2][1]);
  }
  for (int duty = min; duty <= max; duty++) {
    analogWrite(motors[m1][2], duty);
    analogWrite(motors[m2][2], duty);
    delay(1);
  }
  delay(time);
  for (int duty = max; duty >= 0; duty--) {
    analogWrite(motors[m1][2], duty);
    analogWrite(motors[m2][2], duty);
    delay(1);
  }
}
void all_motor_jog(int max, int min, int dir,int time) {

  // ---- SET DIRECTION ----
  if (dir == 0) {                 // FORWARD
    for (int m = 0; m < 4; m++) {
      set_dir_motor(0, motors[m][0], motors[m][1]);
    }

  } else if (dir == 180) {        // BACKWARD
    for (int m = 0; m < 4; m++) {
      set_dir_motor(1, motors[m][0], motors[m][1]);
    }

  } else if (dir == 90) {         // ROTATE RIGHT
    // left side forward
    set_dir_motor(1, motors[0][0], motors[0][1]);
    set_dir_motor(1, motors[2][0], motors[2][1]);

    // right side backward
    set_dir_motor(0, motors[1][0], motors[1][1]);
    set_dir_motor(0, motors[3][0], motors[3][1]);

  } else if (dir == 270) {        // ROTATE LEFT
    // left side backward
    set_dir_motor(0, motors[0][0], motors[0][1]);
    set_dir_motor(0, motors[2][0], motors[2][1]);

    // right side forward
    set_dir_motor(1, motors[1][0], motors[1][1]);
    set_dir_motor(1, motors[3][0], motors[3][1]);

  } else {
    return; // invalid direction
  }

  // ---- RAMP UP ----
  for (int duty = min; duty <= max; duty++) {
    for (int m = 0; m < 4; m++) {
      analogWrite(motors[m][2], duty);
    }
    delay(1);
  }
  delay(time);
  // ---- RAMP DOWN ----
  for (int duty = max; duty >= 0; duty--) {
    for (int m = 0; m < 4; m++) {
      analogWrite(motors[m][2], duty);
    }
    delay(1);
  }
}

void turn_motors(int max, int min, int dir,int time) {
  // 1 = left
  // 0 = right
  if (dir == 1) {
    set_dir_motor(0, motors[0][0], motors[0][1]);
    set_dir_motor(0, motors[1][0], motors[1][1]);
    set_dir_motor(1, motors[2][0], motors[2][1]);
    set_dir_motor(1, motors[3][0], motors[3][1]);
  } else if (dir ==  0) {
    set_dir_motor(1, motors[0][0], motors[0][1]);
    set_dir_motor(1, motors[1][0], motors[1][1]);
    set_dir_motor(0, motors[2][0], motors[2][1]);
    set_dir_motor(0, motors[3][0], motors[3][1]);
  }
  for (int duty = min; duty <= max; duty++) {
    for (int m = 0; m < 4; m++) {
      analogWrite(motors[m][2], duty);
    }
    delay(1);
  }
  delay(time);
  // ---- RAMP DOWN ----
  for (int duty = max; duty >= 0; duty--) {
    for (int m = 0; m < 4; m++) {
      analogWrite(motors[m][2], duty);
    }
    delay(1);
  }
}

void setup() {
  Serial.begin(9600);
  for (int m = 0; m < 4; m++) {
    for (int p = 0; p < 3; p++) {
      pinMode(motors[m][p], OUTPUT);
    }
  }
}


void loop() {
  if (Serial.available()) {
    String command_raw = Serial.readStringUntil('\n');
    String command = getValue(command_raw, ':', 0);
    if (command == "dir_move_all") {
      int arg1 = getValue(command_raw, ':', 1).toInt();
      int arg2 = getValue(command_raw, ':', 2).toInt();
      int arg3 = getValue(command_raw, ':', 3).toInt();
      int arg4 = getValue(command_raw, ':', 4).toInt();
      Serial.printf("cmd %s, arg1 %d, arg2 %d, arg3 %d, arg4 %d\n", command, arg1, arg2, arg3, arg4);
      all_motor_jog(arg1, arg2, arg3, arg4);
    } else if (command == "dir_move_two") {
      int arg1 = getValue(command_raw, ':', 1).toInt();
      int arg2 = getValue(command_raw, ':', 2).toInt();
      int arg3 = getValue(command_raw, ':', 3).toInt();
      int arg4 = getValue(command_raw, ':', 4).toInt();
      Serial.printf("cmd %s, arg1 %d, arg2 %d, arg3 %d, arg4 %d\n", command, arg1, arg2, arg3, arg4);
      motor_jog_double(arg1, arg2, arg3, arg4);
    } else if (command == "turn_all") {
      int arg1 = getValue(command_raw, ':', 1).toInt();
      int arg2 = getValue(command_raw, ':', 2).toInt();
      int arg3 = getValue(command_raw, ':', 3).toInt();
      int arg4 = getValue(command_raw, ':', 4).toInt();
      Serial.printf("cmd %s, arg1 %d, arg2 %d, arg3 %d, arg4 %d\n", command, arg1, arg2, arg3, arg4);
      turn_motors(arg1/4, arg2, arg3, arg4);
    }
  }
  //Serial.printf("echo\n");
  //delay(100);
}

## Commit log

2025-11-23 pcb sensor
    [p-Edge_Cuts.gbr, p-F_Cu.gbr, p.drl]
2025-11-26 wheel star image
2025-11-26 small wheel pulley
    [pulley.stl]
2025-11-26 wheel cap
    [star_cap.stl]
2025-12-14 chassis test
2025-12-21 cam module
    [arc.stl, battery_holder.stl, body.stl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]
2025-12-29 debug version of camera code and base code
2026-01-12 Camera fix (#1)
2026-01-20 driver pcb
    [driver.kicad_pcb, driver.kicad_sch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]
2026-01-23 IR ball: read multiple sensors (#2)
2026-01-23 Mainboard PCB (#3)
    [linesensor.kicad_pcb, linesensor.kicad_sch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]
2026-01-23 linesensor new
    [linesensor.kicad_pcb, linesensor.kicad_sch]
2026-01-25 body robo2 SVG
    [body_2.stl]
2026-01-29 IR ring (#4)
    [mainboard.kicad_sch]
2026-01-30 S3 camera fixup (#5)
    [cam.ino, cam_init.cpp, camera_pins.h]
2026-02-03 CAM: distance sensor & kicker (#6)
    [cam.kicad_pcb, cam.kicad_sch, front_bumper.stl]
2026-02-14 Integration IR ring (#7)
    [IR_case.stl, IR_case_top.stl, body.stl]
2026-02-18 motor test robo x2
2026-02-22 Clone robo x2 pcb (#8)
    [driverx2.kicad_pcb, driverx2.kicad_sch, mainboardx2.kicad_pcb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]
2026-02-25 Four wheels speed (#10)
2026-02-28 Bot2 adoptation (#11)
    [mainboardx2.kicad_pcb, mainboardx2.kicad_sch]
2026-03-01 Turning fix (#12)
    [cam.kicad_sch]
2026-03-03 fixed line sensor PCB
    [linesensor.kicad_pcb, linesensor.kicad_sch]
2026-03-03 Fix goal turning and mode select (#13)
    [base.ino, cam.ino, cam_init.cpp]
2026-03-05 Mag compass (#15)
    [mainboardx2.kicad_sch]
2026-03-07 Line sensor (#16)
    [linesensor.kicad_pcb, mainboard.kicad_pcb]
2026-03-08 Motors target mode (#17)
2026-04-19 Fix lines logic at TU Delft (#19)
    [base.ino]
2026-04-20 mainboard scheme update
    [mainboard.kicad_sch]
